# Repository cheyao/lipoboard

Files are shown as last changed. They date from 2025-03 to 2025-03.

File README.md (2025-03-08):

---
name: "LiPoBoard"
slack_handle: "@Cyao"
github_handle: "@cheyao"
tutorial: NONE
wokwi: NONE
---

# LiPoBoard



A 3-in-one LiPo breakout board:
- LiPo charging
- Overdischarge protection
- Conversion to 3v3 or 5v

Features:
- High efficency (>90%)
- Overdischarge/overcharge protection 
- Selectable 3v3 and 5v
- Single sided design, placable on existing PCBs

The PCB fab price is 3.24 EUR (3.5$), and the components will be ordered from LCSC

Hope everything works first time

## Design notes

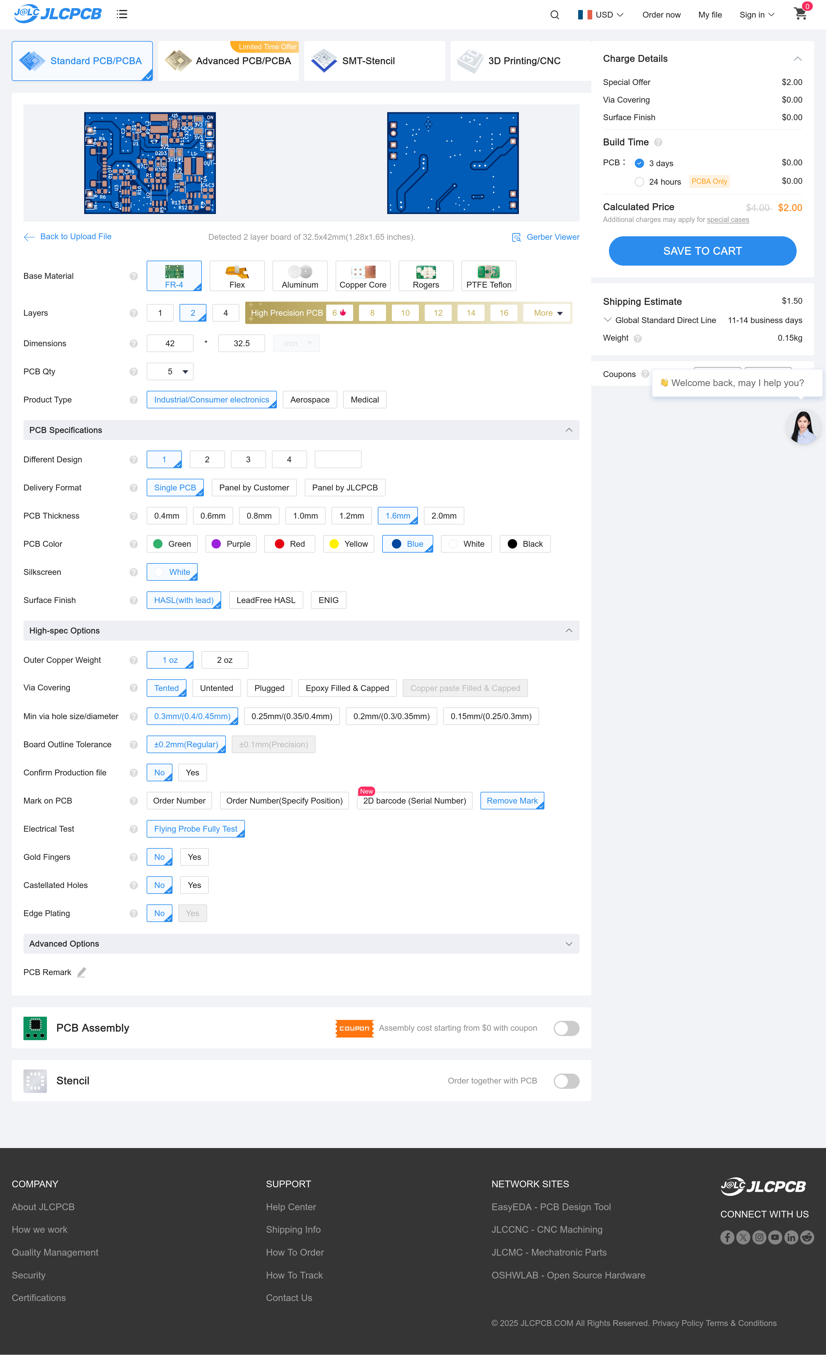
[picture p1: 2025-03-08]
cart.png

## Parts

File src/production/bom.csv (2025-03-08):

Designator | Footprint | Quantity | Value | LCSC Part #
C1, C10, C2, C3, C4, C5, C7, C8, C9 | 0805 | 9 | 10uF | C1713
C11 | 0805 | 1 | 22uF | C45783
C12, C6 | 0805 | 2 | 0.1uF | C38141
D1, D3 | 0603 | 2 | GLED | C22371297
D2 | 0603 | 1 | RLED | C2286
J1 | USB_C_Receptacle_GCT_USB4135-GF-A_6P_TopMnt_Horizontal | 1 | USB_C_Receptacle_PowerOnly_24P | C18357553
L1, L2 | L_TracoPower_TCK-047_5.2x5.8mm | 2 | 2.2uH | C177244
ON | PinHeader_1x02_P2.54mm_Vertical | 1 | SW_DIP_x01 | C126888
R1 | 0805 | 1 | 0.4Ω | C247017
R10 | 0805 | 1 | 2kΩ | C1359
R11 | 0805 | 1 | 100Ω | C17408
R12 | 0805 | 1 | 300kΩ | C17616
R13 | 0805 | 1 | 75kΩ | C17819
R2, R3, R8 | 0805 | 3 | 1kΩ | C2907195
R4, R6 | 0805 | 2 | 5.1kΩ | C2930296
R5 | 0805 | 1 | 1.33kΩ | C2933524
R7 | 0805 | 1 | 10kΩ | C25612
R9 | 0805 | 1 | 470Ω | C2907267
U1 | SOT-583-8 | 1 | TPS2116DRL | C3235557
U2 | SOP-8_3.9x4.9mm_P1.27mm | 1 | TP4056 | C725790
U3 | SOT-23-6_Handsoldering | 1 | DW01A | C2927799
U4 | SOP-8_3.9x4.9mm_P1.27mm | 1 | TP5188 | C29075512
U5 | Texas_DRC0010J_ThermalVias | 1 | TPS63001 | C28060

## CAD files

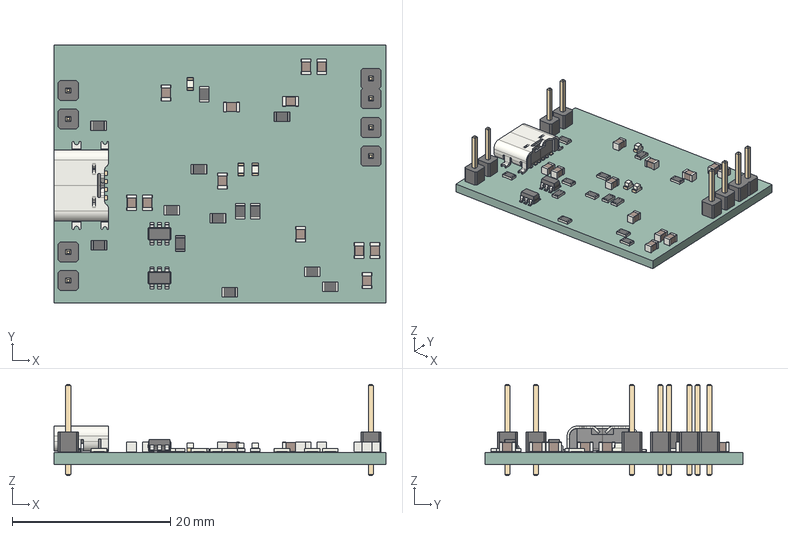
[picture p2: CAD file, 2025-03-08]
src/lipoboard.step
41.9 x 32.5 x 11.5 mm
R_0805_2012Metric x 13
PinHeader_1x01_P2.54mm_Vertical x 6
C_0805_2012Metric x 12
USB_C_Receptacle_GCT_USB4135-GF-A_6P_TopMnt_Horizontal
SOT-23-6 x 2
LED_0603_1608Metric x 3
PinHeader_1x02_P2.54mm_Vertical
lipoboard_PCB

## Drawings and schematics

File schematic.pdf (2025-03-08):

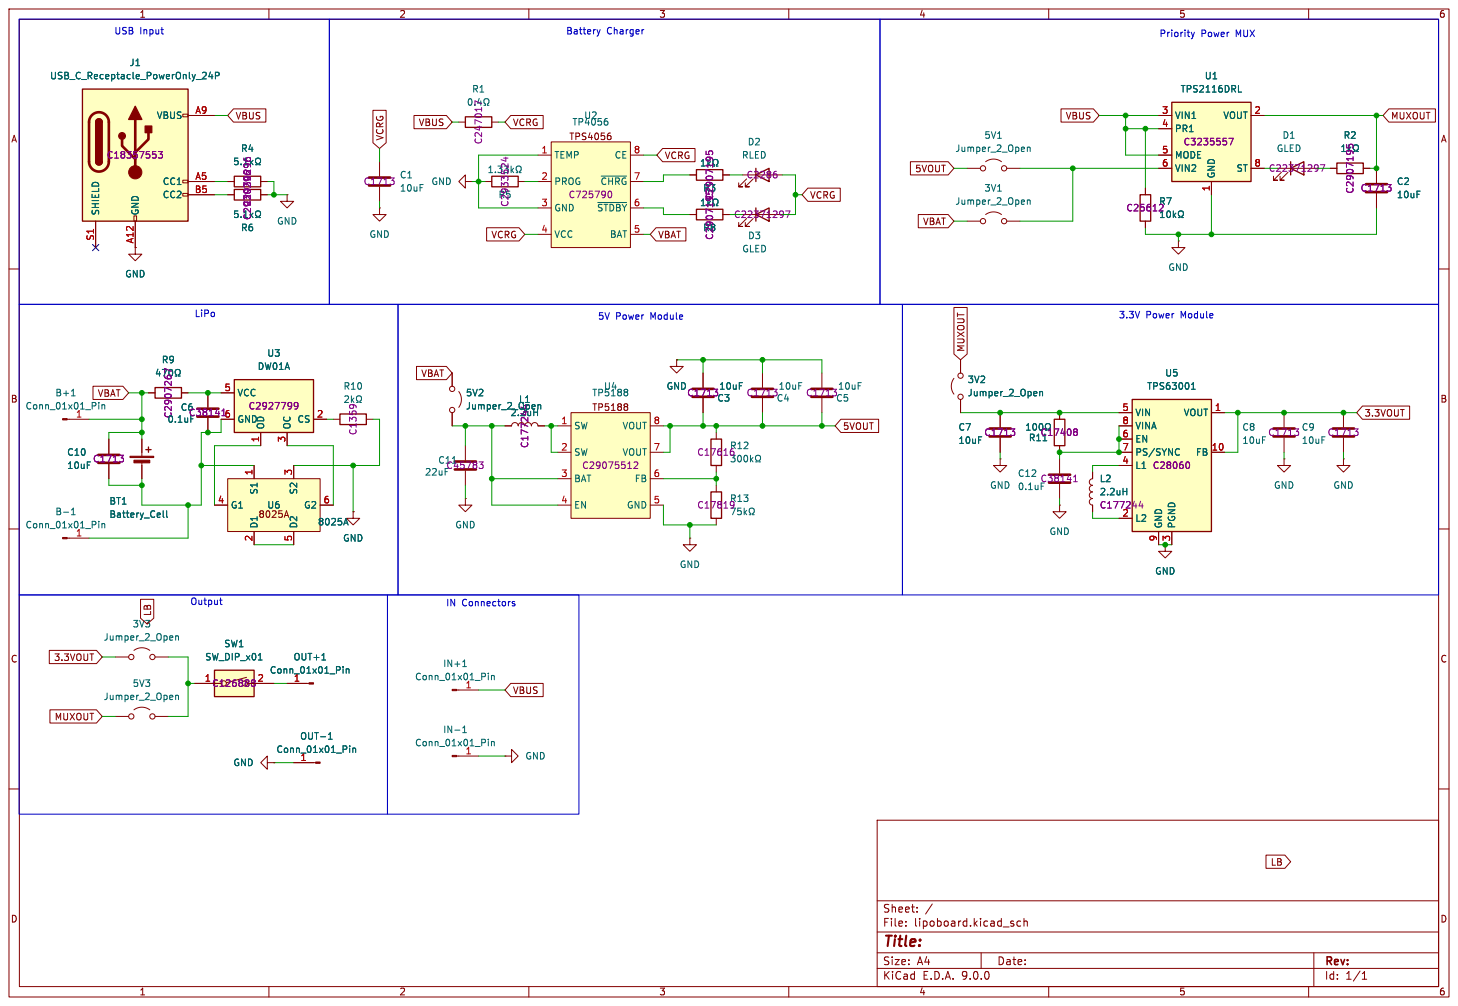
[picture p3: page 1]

U5 TPS63001 C28060 VIN 5 VINA 8 EN 6 PS/SYNC 7

VIN 5 VINA 8 EN 6 PS/SYNC 7

Id: 1/1 Title: File: lipoboard.kicad_sch Sheet: /

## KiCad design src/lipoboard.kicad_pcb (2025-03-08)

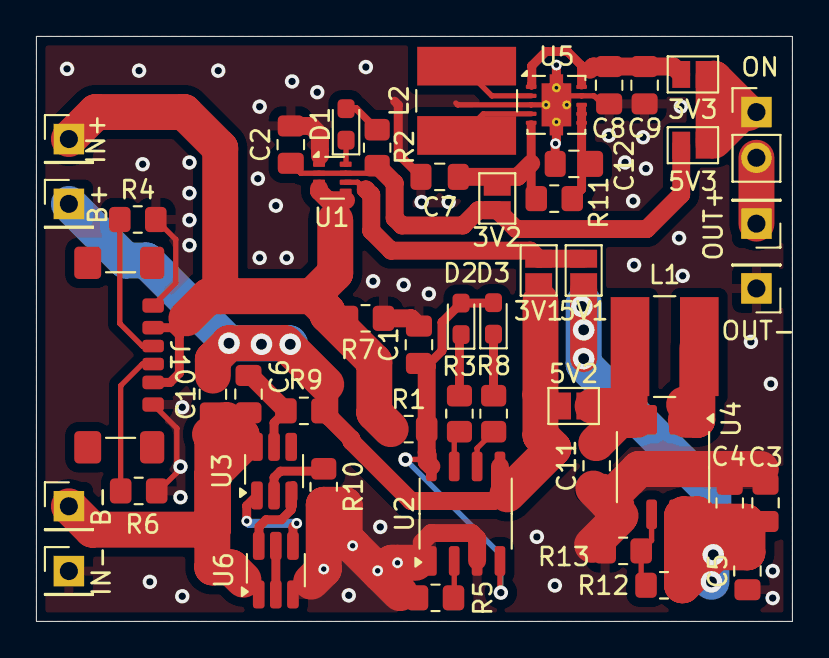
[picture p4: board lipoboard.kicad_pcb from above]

Board: 2 copper layers, 42.0 x 32.5 mm, 50 parts (0 on the bottom side), 32 nets.

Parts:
3V1, 3V2, 3V3, 5V1, 5V2, 5V3: Jumper_2_Open; SolderJumper-2_P1.3mm_Open_Pad1.0x1.5mm
B+: Conn_01x01_Pin; PinHeader_1x01_P2.54mm_Vertical
B-: Conn_01x01_Pin; PinHeader_1x01_P2.54mm_Vertical
C1, C2, C3, C4, C5, C7, C8, C9, C10: 10uF; C_0805_2012Metric_Pad1.18x1.45mm_HandSolder
C6, C12: 0.1uF; C_0805_2012Metric_Pad1.18x1.45mm_HandSolder
C11: 22uF; C_0805_2012Metric_Pad1.18x1.45mm_HandSolder
D1, D3: GLED; LED_0603_1608Metric_Pad1.05x0.95mm_HandSolder
D2: RLED; LED_0603_1608Metric_Pad1.05x0.95mm_HandSolder
IN+: Conn_01x01_Pin; PinHeader_1x01_P2.54mm_Vertical
IN-: Conn_01x01_Pin; PinHeader_1x01_P2.54mm_Vertical
J1: USB_C_Receptacle_PowerOnly_24P; USB_C_Receptacle_GCT_USB4135-GF-A_6P_TopMnt_Horizontal
L1, L2: 2.2uH; L_TracoPower_TCK-047_5.2x5.8mm
ON: SW_DIP_x01; PinHeader_1x02_P2.54mm_Vertical
OUT+: Conn_01x01_Pin; PinHeader_1x01_P2.54mm_Vertical
OUT-: Conn_01x01_Pin; PinHeader_1x01_P2.54mm_Vertical
R1: 0.4Ω; R_0805_2012Metric_Pad1.20x1.40mm_HandSolder
R2, R3, R8: 1kΩ; R_0805_2012Metric_Pad1.20x1.40mm_HandSolder
R4, R6: 5.1kΩ; R_0805_2012Metric_Pad1.20x1.40mm_HandSolder
R5: 1.33kΩ; R_0805_2012Metric_Pad1.20x1.40mm_HandSolder
R7: 10kΩ; R_0805_2012Metric_Pad1.20x1.40mm_HandSolder
R9: 470Ω; R_0805_2012Metric_Pad1.20x1.40mm_HandSolder
R10: 2kΩ; R_0805_2012Metric_Pad1.20x1.40mm_HandSolder
R11: 100Ω; R_0805_2012Metric_Pad1.20x1.40mm_HandSolder
R12: 300kΩ; R_0805_2012Metric_Pad1.20x1.40mm_HandSolder
R13: 75kΩ; R_0805_2012Metric_Pad1.20x1.40mm_HandSolder
U1: TPS2116DRL; SOT-583-8
U2: TP4056; SOP-8_3.9x4.9mm_P1.27mm
U3: DW01A; SOT-23-6_Handsoldering
U4: TP5188; SOP-8_3.9x4.9mm_P1.27mm
U5: TPS63001; Texas_DRC0010J_ThermalVias
U6: 8025A; SOT-23-6_Handsoldering

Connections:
3.3VOUT: 3V3.1 (A), C8.1, C9.1, U5.1 (VOUT), U5.10 (FB)
5VOUT: 5V1.1 (A), C3.1, C4.1, C5.1, R12.1, U4.7 (VOUT), U4.8 (VOUT)
GND: C1.2, C2.2, C3.2, C4.2, C5.2, C7.2, C8.2, C9.2, C11.2, C12.2, IN-.1, J1.A12 (GND), J1.B12 (GND), OUT-.1, R4.2, R5.2, R6.2, R7.1, R10.2, R13.1, U1.1 (GND), U2.1 (TEMP), U2.3 (GND), U4.5 (GND), U5.3 (PGND), U5.9 (GND), U5.11 (PGND), U6.3 (S2)
MUXOUT: 3V2.2 (B), 5V3.1 (A), C2.1, R2.2, U1.2 (VOUT), U1.7 (VOUT)
unnamed: 3V1.2 (B), 5V1.2 (B), U1.6 (VIN2)
unnamed: 3V2.1 (A), C7.1, R11.2, U5.5 (VIN)
unnamed: 3V3.2 (B), 5V3.2 (B), ON.1
unnamed: 5V2.2 (B), C11.1, L1.1, U4.3 (BAT), U4.4 (EN)
unnamed: B-.1, C6.2, C10.2, U3.6 (GND), U6.1 (S1)
unnamed: D1.2 (A), R2.1
unnamed: D1.1 (K), U1.8 (ST)
unnamed: D2.1 (K), R3.1
unnamed: D3.1 (K), R8.1
unnamed: J1.A5 (CC1), R4.1
unnamed: J1.B5 (CC2), R6.1
unnamed: L1.2, U4.1 (SW), U4.2 (SW)
unnamed: ON.2, OUT+.1
unnamed: R5.1, U2.2 (PROG)
unnamed: R3.2, U2.7 (~CHRG)
unnamed: R8.2, U2.6 (~STDBY)
unnamed: R10.1, U3.2 (CS)
unnamed: U3.3 (OC), U6.6 (G2)
unnamed: U3.1 (OD), U6.4 (G1)
unnamed: C6.1, R9.2, U3.5 (VCC)
unnamed: R12.2, R13.2, U4.6 (FB)
unnamed: C12.1, R11.1, U5.6 (EN), U5.7 (PS/SYNC), U5.8 (VINA)
unnamed: L2.2, U5.4 (L1)
unnamed: L2.1, U5.2 (L2)
unnamed: U6.2 (D1), U6.5 (D2)
VBAT: 3V1.1 (A), 5V2.1 (A), B+.1, C10.1, R9.1, U2.5 (BAT)
VBUS: IN+.1, J1.A9 (VBUS), J1.B9 (VBUS), R1.1, R7.2, U1.3 (VIN1), U1.4 (PR1), U1.5 (MODE)
VCRG: C1.1, D2.2 (A), D3.2 (A), R1.2, U2.4 (VCC), U2.8 (CE)

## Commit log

2025-03-08 Add readme
    [bom.csv, designators.csv, lipoboard.kicad_pcb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]
2025-03-08 Change dir structure
    [bom.csv, designators.csv, lipoboard.kicad_pcb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]
